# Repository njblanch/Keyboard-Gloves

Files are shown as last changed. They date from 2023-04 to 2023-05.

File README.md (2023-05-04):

# Keyboard-Gloves
### Skyler Heininger and Nathan Blanchard

The programs present within this repository are testing and final scripts. Additionally, there are 11 STL files that were used in 3d printing.

## Raspberry Pi Programs
The program titled "test2.py"
(while clearly not the first test.py file) was used rigorously for testing output of the MCP3008s. This 
displayed raw data to the user and if a certain potentiometer was hitting the threshold values. This code
was adapted in "inpTest2.py" (clearly also not the first of the inpTest.py iterations) to instead return 
binary if a potentiometer passed threshold. Additionally, inpTest2.py made the large jump of connecting to a
server, and sending the data. It turns out that the TCP socket connection used for this is much, much slower 
than the MCP3008 can return values, which is why inpTest2.py features a higher value to sleep upon each 
iteration of the while loop. Even still, multiple values can pile up in the TCP queue before it is sent to 
the server, causing concatenation of readouts. 

## Server Side Program
"blueServer.py" handles the inputs from inpTest2.py using the function "getState". This function takes a string input, 
splits the inputted string by commas, and returns a tuple of the first five inputs. This allows us to handle
concatenation of the readings in the TCP queue as we will only have one reading from each time the client 
sends over data. This data is also valid to be used within the "typeOutput" function, which takes the two 
tuples that were returned from running getState on inputs from each raspberry pi. TypeOutput then ____.
The TCP connection was handled in main, using the socket package and two different ports to accommodate 
two simultaneously-running socket connections. At any point, if a socket server fails, or any of the programs
are terminated, all the socket connections are closed and programs are terminated.

## Keyboard Gloves Commands
All commands/gestures for the keyboard gloves, as well as a brief explanation of how this layout works, can be found 
in the "Keyboard Gloves Layout.docx" document. The user should read this document before using the keyboard gloves to 
better understand functionality and learn what inputs are available and the gestures required to type them.

## stl Files
All stl files that were printed and included in the final version of they Keyboard Gloves have been included in the "stl files" folder.

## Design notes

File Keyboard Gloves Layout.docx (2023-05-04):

Keyboard Gloves Layout

Overview:

The inputs from each hand will be represented by a string of 5 characters from {0, 1}, where 0 represents finger extension and 1 represents finger flexion. The positions of these characters are associated with the location of the fingers on each hand when in a typing position like that of a traditional keyboard. The inputs from the left hand are used to determine the set of characters used, and the right-hand inputs are used to select which key to output. Additionally, the left-hand thumb will be used as a modifier key to specify capitalized letters and alternate punctuation and the right-hand thumb will be associated with the space and backspace key depending on the position of the left-hand thumb. Also note that the keybinds took inspiration from on a traditional qwerty keyboard layout to help the user have an easy transition from a qwerty keyboard to using the Keyboard Gloves. A value of 1 for the left hand pinky represents the left side of the keyboard and a value of 1 for the left hand index finger represents the right side of the keyboard, with the 3rd and 4th fingers specifying the row of keys that the user wants to type from.

Example:

00010 00010

This string of characters will result from bending the left-hand index finger and the right-hand ring finger, with all other fingers extended and will type the character “o” being typed.

Keybinds:

Left Hand Input | Right Hand Input | Output
xxxx0 | 10000 | space
xxxx1 | 10000 | backspace
00100 | 01000 | ‘
00100 | 00100 | ,
00100 | 00010 | .
00100 | 00001 | enter
00101 | 01000 | “
00101 | 00100 | (
00101 | 00010 | )
00101 | 00001 | :
10000 | 01000 | q
10000 | 00100 | w
10000 | 00010 | e
10000 | 00001 | r
11000 | 01000 | a
11000 | 00100 | s
11000 | 00010 | d
11000 | 00001 | f
11100 | 01000 | z
11100 | 00100 | x
11100 | 00010 | c
11100 | 00001 | v
00010 | 01000 | u
00010 | 00100 | i
00010 | 00010 | o
00010 | 00001 | p
00110 | 01000 | j
00110 | 00100 | k
00110 | 00010 | l
00110 | 00001 | ;
01110 | 01000 | b
01110 | 00100 | n
01110 | 00010 | m
01110 | 00001 | /
01100 | 01000 | t
01100 | 00100 | g
01100 | 00010 | y
01100 | 00001 | h
10001 | 01000 | Q
10001 | 00100 | W
10001 | 00010 | E
10001 | 00001 | R
11001 | 01000 | A
11001 | 00100 | S
11001 | 00010 | D
11001 | 00001 | F
11101 | 01000 | Z
11101 | 00100 | X
11101 | 00010 | C
11101 | 00001 | V
00011 | 01000 | U
00011 | 00100 | I
00011 | 00010 | O
00011 | 00001 | P
00111 | 01000 | J
00111 | 00100 | K
00111 | 00010 | L
00111 | 00001 | !
01111 | 01000 | B
01111 | 00100 | N
01111 | 00010 | M
01111 | 00001 | ?
01101 | 01000 | T
01101 | 00100 | G
01101 | 00010 | Y
01101 | 00001 | H
01000 | 01000 | 0
01000 | 00100 | 1
01000 | 00010 | -
01000 | 00001 | +
10010 | 01000 | 2
10010 | 00100 | 3
10010 | 00010 | 4
10010 | 00001 | 5
10011 | 01000 | 6
10011 | 00100 | 7
10011 | 00010 | 8
10011 | 00001 | 9

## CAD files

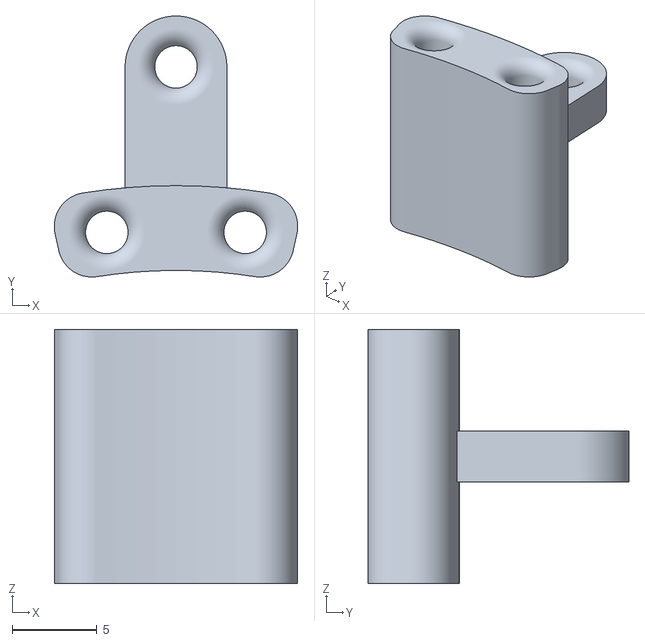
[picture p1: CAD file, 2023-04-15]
stl files/midcapFinger.stl
14.4 x 15.4 x 15.0

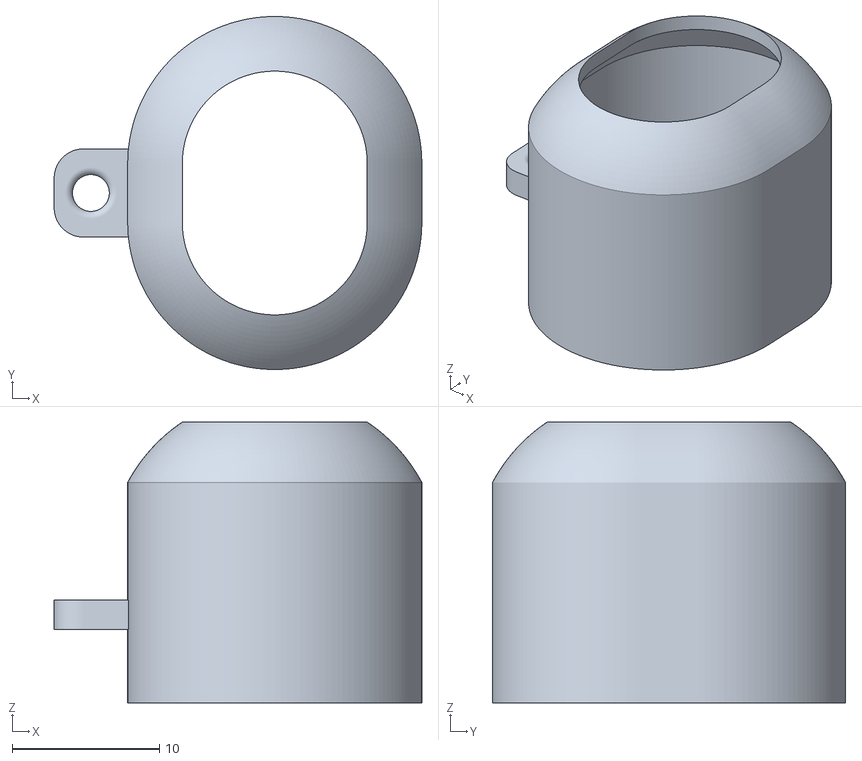
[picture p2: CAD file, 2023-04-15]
stl files/endCapThumb.stl
25.0 x 24.0 x 19.1

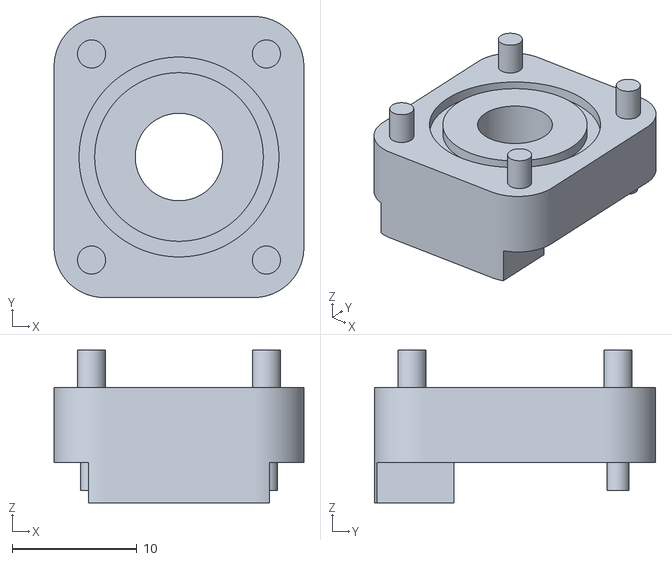
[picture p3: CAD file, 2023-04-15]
stl files/bottomSpool.stl
20.0 x 22.5 x 12.2

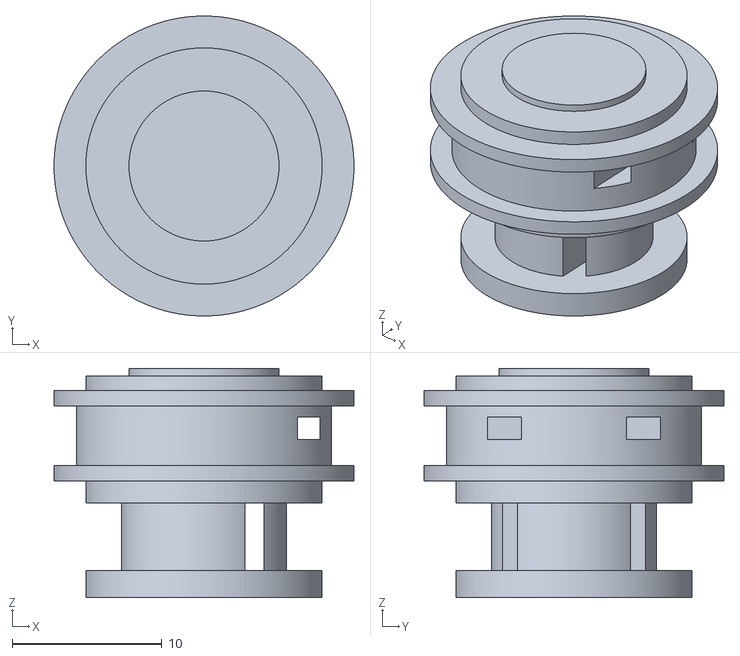
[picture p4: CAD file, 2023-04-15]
stl files/Spool.stl
20.0 x 20.0 x 15.3

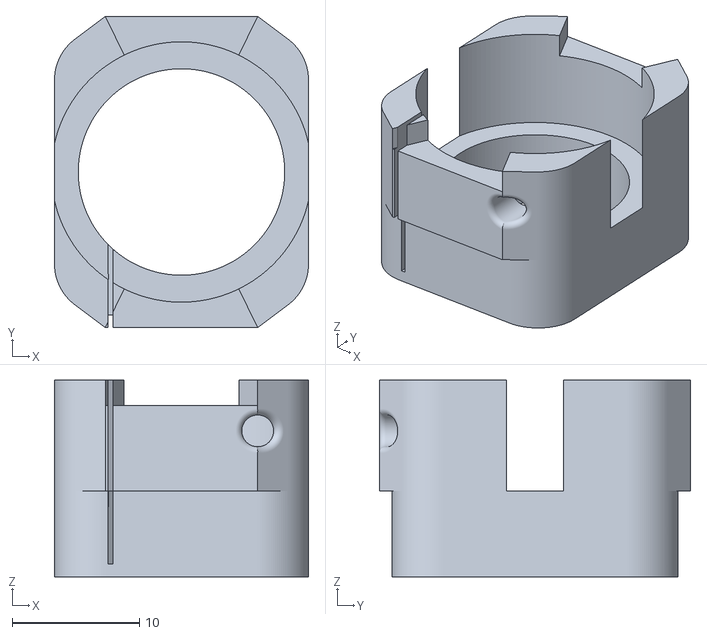
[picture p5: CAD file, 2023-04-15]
stl files/midSpool.stl
20.0 x 24.5 x 15.5

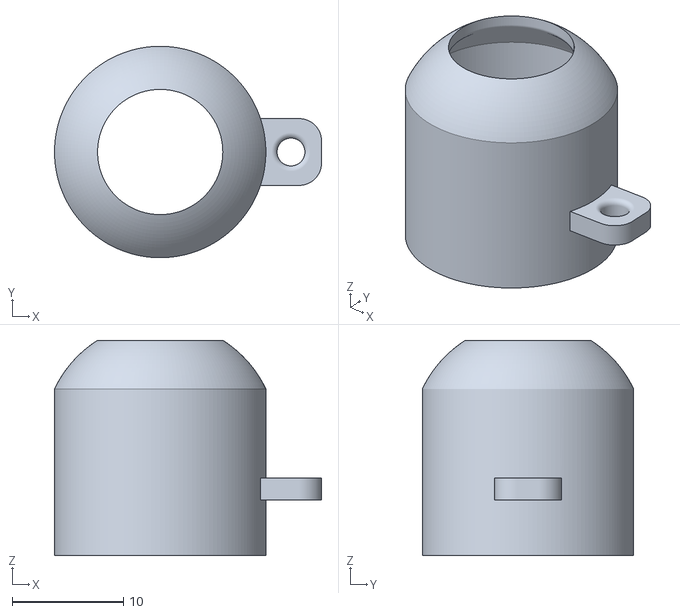
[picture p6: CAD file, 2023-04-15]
stl files/endCapFingers.stl
24.0 x 19.0 x 19.4

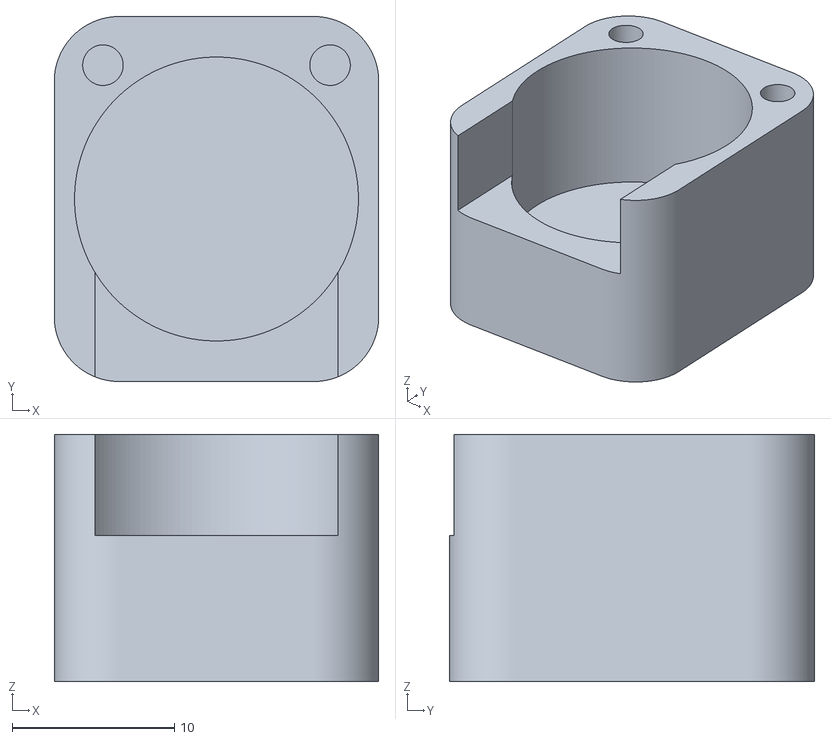
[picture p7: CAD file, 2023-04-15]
stl files/potentiometerBottom.stl
20.0 x 22.5 x 15.2

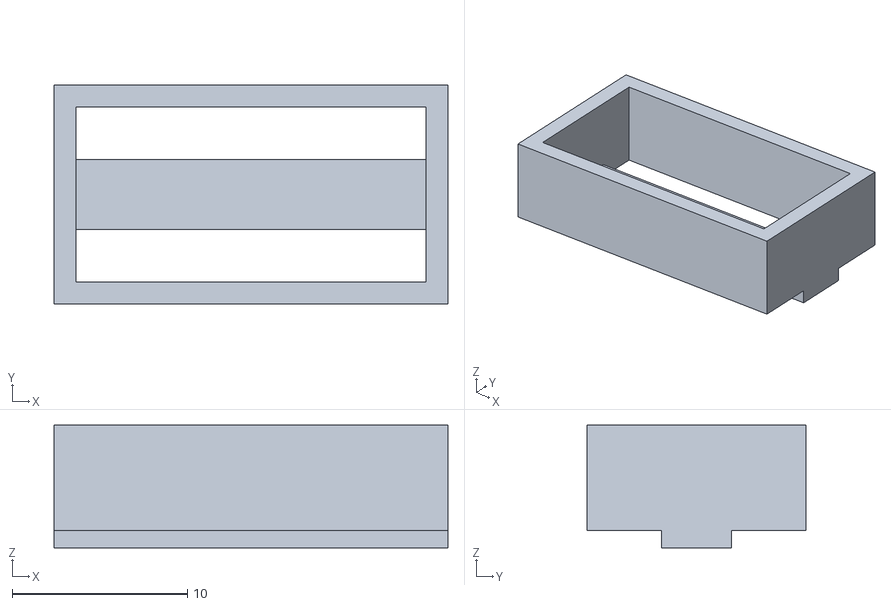
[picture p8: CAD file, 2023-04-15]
stl files/MCPHoldTop.stl
22.5 x 12.5 x 7.00

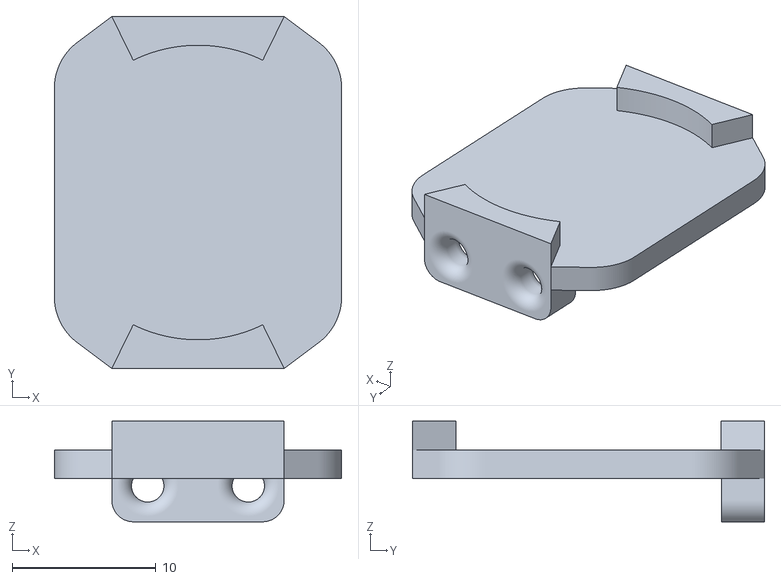
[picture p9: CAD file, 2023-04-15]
stl files/topSpool.stl
20.0 x 24.5 x 7.00

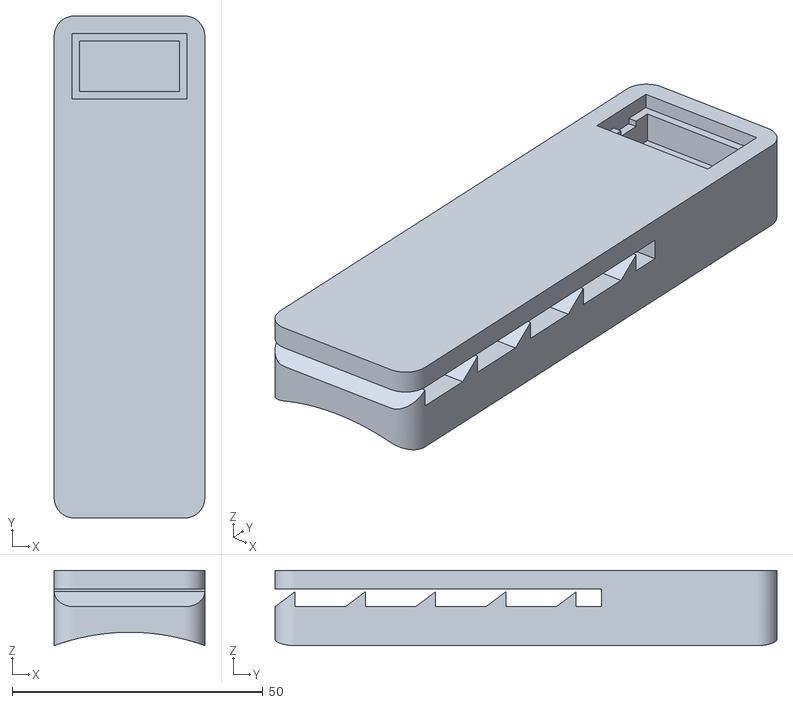
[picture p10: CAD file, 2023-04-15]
stl files/armBand.stl
30.0 x 100.0 x 15.0

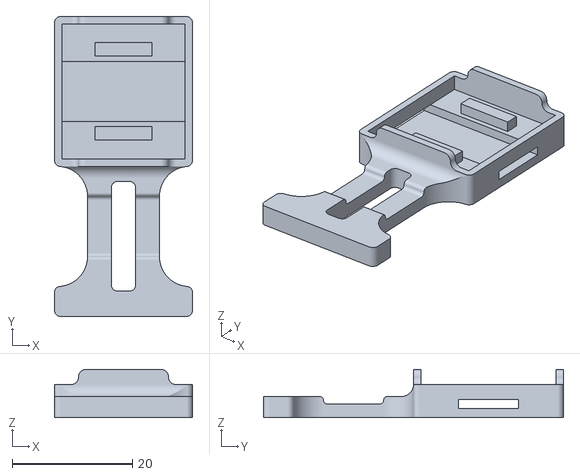
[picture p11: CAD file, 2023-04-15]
stl files/potentiometerHand.stl
23.0 x 50.0 x 8.00

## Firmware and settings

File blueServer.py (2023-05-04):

import socket
import pyautogui

# All socket server scripting is taken from this guide:
# https://realpython.com/python-sockets/#multi-connection-client-and-server

# Left hand is port 50001, Right hand 50002
port1 = 50001
port2 = 50002
# Mac address is the IPV4 wifi address of the host computer. 
macAddress = ""
backlog = 5
size = 1024

# Values for neutral, down
NEUTRAL = 0
PRESS = 1

# Dictionary for determining output
keyDict = {"0,0,1,0,0," + "0,1,0,0,0,": "'", "0,0,1,0,0," + "0,0,1,0,0,": ",", "0,0,1,0,0," + "0,0,0,1,0,": ".",
           "0,0,1,0,1," + "0,1,0,0,0,": "\"", "0,0,1,0,1," + "0,0,1,0,0,": "(", "0,0,1,0,1," + "0,0,0,1,0,": ")", "0,0,1,0,1," + "0,0,0,0,1,": ":",
           "1,0,0,0,0," + "0,1,0,0,0,": "q", "1,0,0,0,0," + "0,0,1,0,0,": "w", "1,0,0,0,0," + "0,0,0,1,0,": "e", "1,0,0,0,0," + "0,0,0,0,1,": "r",
           "1,1,0,0,0," + "0,1,0,0,0,": "a", "1,1,0,0,0," + "0,0,1,0,0,": "s", "1,1,0,0,0," + "0,0,0,1,0,": "d", "1,1,0,0,0," + "0,0,0,0,1,": "f",
           "1,1,1,0,0," + "0,1,0,0,0,": "z", "1,1,1,0,0," + "0,0,1,0,0,": "x", "1,1,1,0,0," + "0,0,0,1,0,": "c", "1,1,1,0,0," + "0,0,0,0,1,": "v",
           "0,0,0,1,0," + "0,1,0,0,0,": "u", "0,0,0,1,0," + "0,0,1,0,0,": "i", "0,0,0,1,0," + "0,0,0,1,0,": "o", "0,0,0,1,0," + "0,0,0,0,1,": "p",
           "0,0,1,1,0," + "0,1,0,0,0,": "j", "0,0,1,1,0," + "0,0,1,0,0,": "k", "0,0,1,1,0," + "0,0,0,1,0,": "l", "0,0,1,1,0," + "0,0,0,0,1,": ";",
           "0,1,1,1,0," + "0,1,0,0,0,": "b", "0,1,1,1,0," + "0,0,1,0,0,": "n", "0,1,1,1,0," + "0,0,0,1,0,": "m", "0,1,1,1,0," + "0,0,0,0,1,": "/",
           "0,1,1,0,0," + "0,1,0,0,0,": "t", "0,1,1,0,0," + "0,0,1,0,0,": "g", "0,1,1,0,0," + "0,0,0,1,0,": "y", "0,1,1,0,0," + "0,0,0,0,1,": "h",
           "1,0,0,0,1," + "0,1,0,0,0,": "Q", "1,0,0,0,1," + "0,0,1,0,0,": "W", "1,0,0,0,1," + "0,0,0,1,0,": "E", "1,0,0,0,1," + "0,0,0,0,1,": "R",
           "1,1,0,0,1," + "0,1,0,0,0,": "A", "1,1,0,0,1," + "0,0,1,0,0,": "S", "1,1,0,0,1," + "0,0,0,1,0,": "D", "1,1,0,0,1," + "0,0,0,0,1,": "F",
           "1,1,1,0,1," + "0,1,0,0,0,": "Z", "1,1,1,0,1," + "0,0,1,0,0,": "X", "1,1,1,0,1," + "0,0,0,1,0,": "C", "1,1,1,0,1," + "0,0,0,0,1,": "V",
           "0,0,0,1,1," + "0,1,0,0,0,": "U", "0,0,0,1,1," + "0,0,1,0,0,": "I", "0,0,0,1,1," + "0,0,0,1,0,": "O", "0,0,0,1,1," + "0,0,0,0,1,": "P",
           "0,0,1,1,1," + "0,1,0,0,0,": "J", "0,0,1,1,1," + "0,0,1,0,0,": "K", "0,0,1,1,1," + "0,0,0,1,0,": "L", "0,0,1,1,1," + "0,0,0,0,1,": "!",
           "0,1,1,1,1," + "0,1,0,0,0,": "B", "0,1,1,1,1," + "0,0,1,0,0,": "N", "0,1,1,1,1," + "0,0,0,1,0,": "M", "0,1,1,1,1," + "0,0,0,0,1,": "?",
           "0,1,1,0,1," + "0,1,0,0,0,": "T", "0,1,1,0,1," + "0,0,1,0,0,": "G", "0,1,1,0,1," + "0,0,0,1,0,": "Y", "0,1,1,0,1," + "0,0,0,0,1,": "H",
           "0,1,0,0,0," + "0,1,0,0,0,": "0", "0,1,0,0,0," + "0,0,1,0,0,": "1", "0,1,0,0,0," + "0,0,0,1,0,": "+", "0,1,0,0,0," + "0,0,0,0,1,": "-",
           "1,0,0,1,0," + "0,1,0,0,0,": "2", "1,0,0,1,0," + "0,0,1,0,0,": "3", "1,0,0,1,0," + "0,0,0,1,0,": "4", "1,0,0,1,0," + "0,0,0,0,1,": "5",
           "1,0,0,1,1," + "0,1,0,0,0,": "6", "1,0,0,1,1," + "0,0,1,0,0,": "7", "1,0,0,1,1," + "0,0,0,1,0,": "8", "1,0,0,1,1," + "0,0,0,0,1,": "9"}

# Use these threshold values to create states (aka finger positions)
# When these positions change, then take an input, or nothing if neutral
def getState(stringPos):
    stringPos = stringPos.split(",")
    # sometimes the socket will send more than one set of states at once
    # This can still be accepted since this will only take the first set of
    # inputs of that string, not the whole thing

    # print(stringPos)
    tPos = float(stringPos[0])
    pPos = float(stringPos[1])
    mPos = float(stringPos[2])
    rPos = float(stringPos[3])
    piPos = float(stringPos[4])
    return tPos, pPos, mPos, rPos, piPos


# typeOutput simply takes in the data of the right and left hands,
# and then determines what to type.
def typeOutput(key):
    try:
        if key[10] == "1":
            if key[8] == "0":
                pyautogui.write(" ")
                return
            else:
                pyautogui.press("backspace")
                return
        elif key == "0,0,1,0,0,0,0,0,0,1,":
            pyautogui.press("enter")
        else:
            pyautogui.write(keyDict.get(key))
    except:
        return
    return
''

def main():

    # s1 is left hand, s2 right hand
    s1 = socket.socket(socket.AF_INET, socket.SOCK_STREAM)
    s1.bind((macAddress, port1))
    s1.listen(backlog)
    s2 = socket.socket(socket.AF_INET, socket.SOCK_STREAM)
    s2.bind((macAddress, port2))
    s2.listen(backlog)

    print("Server started")

    # Much of this doesn't do that much, but may need more logic in future
    stateCheck1 = (0, 0, 0, 0, 0)
    stateCheck2 = (0, 0, 0, 0, 0)
    state1 = (0, 0, 0, 0, 0)
    state2 = (0, 0, 0, 0, 0)
    data1 = "1,1,1,1,1,"
    data2 = "1,1,1,1,1,"

    # Try except statement with embedded loop is the entire server. 
    try:
        # Make connection with the two raspberry pis
        client1, address1 = s1.accept()
        print("First connection accepted")
        client2, address2 = s2.accept()
        print("Accepted both connections")
        # Infinite while loop unless terminated by a crash on any of the 3 computers or
        # a given input results in a break
        while 1:
            # receiving the data and parsing it
            data1 = client1.recv(size)
            data2 = client2.recv(size)
            if data1:
                data1 = data1.decode('utf-8')
            if data2:
                data2 = data2.decode('utf-8')
            print(f"lh: {str(data1):10}  rh: {str(data2):10}")
            state1 = getState(data1)
            state2 = getState(data2)
            
            # If the right hand changes in state, then go to type something.
            # This is only for the right hand since the left hand is needed for 
            # changing what the right hand can type.
            if state2 != stateCheck2:
                typeOutput(f"{str(data1):10}{str(data2):10}")
                # updating statechecks so can determine the next time the right hand changes
                stateCheck1 = state1
                stateCheck2 = state2
    except:
        # Close everything down
        print("Closing socket")
        client1.close()
        s1.close()
        client2.close()
        s2.close()

main()

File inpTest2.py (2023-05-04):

from time import sleep
from gpiozero import MCP3008
import socket

# Default threshold values
# These need to be adjusted for each user depending on hand size
T = .8
P = .8
M = .8
R = .8
PI = .8

# The following documentation was used for the MCP3008 scripting:
# https://gpiozero.readthedocs.io/en/stable/api_spi.html#analog-to-digital-converters-adc

# For the Socket connection, the following guide was used:
# https://realpython.com/python-sockets/#multi-connection-client-and-server

# The mac address is simply a string of the IPV4 address of the devices WIFI chip
serverMac = ""
# port = 50001
# or
# port = 50002

# Initialize MCP3008 channels
inp1 = MCP3008(channel=0, clock_pin=11, mosi_pin=10, miso_pin=9, select_pin=8)
inp2 = MCP3008(channel=1, clock_pin=11, mosi_pin=10, miso_pin=9, select_pin=8)
inp3 = MCP3008(channel=2, clock_pin=11, mosi_pin=10, miso_pin=9, select_pin=8)
inp4 = MCP3008(channel=3, clock_pin=11, mosi_pin=10, miso_pin=9, select_pin=8)
inp5 = MCP3008(channel=4, clock_pin=11, mosi_pin=10, miso_pin=9, select_pin=8)


connected = False
s = socket.socket(socket.AF_INET, socket.SOCK_STREAM)
while not connected:
    try:
        s.connect((serverMac, port))
        connected = True
    except:
        continue
while 1:
    # string1 is simply the string values, it can be ommitted in this iteration
    # Ommitting this hardly saves time, this is still incredibly fast and 
    # runs into queue concatenation.
    # string1 = str(inp1.value) + "," + str(inp2.value) + "," + str(inp3.value) + "," + str(inp4.value) + "," + str(inp5.value) + ","
    
    # If statements to determine a "press". Threshold values are found through testing
    # This takes some of the time burden off of the server side
    if inp1.value < T:
        Tpress = 1
    else:
        Tpress = 0

    if inp2.value < P:
        Ppress = 1
    else:
        Ppress = 0

    if inp3.value < M:
        Mpress = 1
    else:
        Mpress = 0

    if inp4.value < R:
        Rpress = 1
    else:
        Rpress = 0

    if inp5.value < PI:
        Pipress = 1
    else:
        Pipress = 0

    # print(string1)
    # text = str(string1)
    # The comma at the end is what handles the queue concatenation.
    # The function getState of blueServer.py will take only the first five values, 
    # after splitting by ",". Therefore, adding the comma will make concatenated values handled.
    state = str(Tpress) + "," + str(Ppress) + "," + str(Mpress) + "," + str(Rpress) + "," + str(Pipress) + ","
    print(state)
    s.send(bytes(state, 'UTF-8'))
    sleep(.02)
